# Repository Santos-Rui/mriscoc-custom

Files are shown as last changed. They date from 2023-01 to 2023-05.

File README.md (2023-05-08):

# TODO

- Start end g-code

<br/><br/>
<br/><br/>

# Instructions Boreal Spring 2023

##  Compile

 - Option STM32F10ERE_creality 512k

<br/><br/>

## Base Config 

- Ender3V2-427-BLTUBL-T5-MPC (MPC -> Alternative to PID)

<br/><br/>

## Extra Z Stepepr

### pins_CREALITY_V4.h

- Commentar esta merda, ou não dá
```
(M)// #if HOTENDS > 1 || E_STEPPERS > 1
(M)//   #error "Creality V4 only supports one hotend / E-stepper. Comment out this line to continue."
(M)// #endif
```

- Free pin to have 3 free ones for extra stepper full control
```
(M) #define Z_MIN_PROBE_PIN                   PA7   // BLTouch IN
```

- Define new pins
```
(+) #define E1_ENABLE_PIN                       PB1 //(connect to ground to always enable)
(+) #define E1_STEP_PIN                         PA14 //SWCLK (STEP - pulled low)
(+) #define E1_DIR_PIN                          PA13 //SWIO  (DIR - pulled high)
```

### Configuration.h
```
(+) #define Z2_DRIVER_TYPE  TMC2208_STANDALONE   // Ender Configs - Extra Z
```
<br/><br/>

## Probe Offset 
### Configuration.h

```
(M) #define NOZZLE_TO_PROBE_OFFSET { -44, 3, -4.28 }
```
<br/><br/>

## Jerk
### Configuration.h
```
(M)  #define DEFAULT_XJERK 15.0  // Ender Configs
(M)  #define DEFAULT_YJERK 15.0  // Ender Configs
```
<br/><br/>

## Sound
### Configuration_adv.h
```
(M) //#define SOUND_ON_DEFAULT    // Buzzer/speaker default enabled state
```
<br/><br/>

## Default steps
### Configuration.h
```
(M) //#define DEFAULT_AXIS_STEPS_PER_UNIT   { 80, 80, 400, 96.6 }  // Ender Configs
```
<br/><br/>

## Temp Sensor
### Configuration.h
```
(M) #define TEMP_SENSOR_0 5  // Volcano thermistor
```
<br/><br/>

## Live Move
### dwin.cpp
```
(M) bool EnableLiveMove = true;
```
<br/><br/>

## Max/Min Positions
### Configuration.h

```
// The size of the printable area
#define X_BED_SIZE 230  // MRiscoC Max usable bed size
#define Y_BED_SIZE 230  // MRiscoC Max usable bed size
```
```
(M)#define X_MAX_POS 249
(M)#define Y_MAX_POS 230  
(M)#define Z_MAX_POS 249 
```
<br/><br/>

 ## Mesh
### Configuration.h

```
(M) #define MESH_INSET 10           
(M) #define GRID_MAX_POINTS_X 7     
```
### Configuration_adv.h
```
#define X_MIN_POS 0  // MRiscoC Stock physical limit
#define Y_MIN_POS 0  // MRiscoC Stock physical limit
(M)#define Z_MIN_POS 0
(M)#define Y_MAX_POS 220  // 
(M)#define Z_MAX_POS 249  // 
```
<br/><br/>

 ## Tramming
### Configuration.h

```
(M)  #define BED_TRAMMING_INSET_LFRB { 10, 10, 10, 10 }    
```

<br/><br/>

## Temps

### Configuration.h

```
(M) #define PROBING_BED_TEMP     60
(M)  #define LEVELING_BED_TEMP     60
```

<br/><br/>

 ## Bed PID
### Configuration.h

```
(M)  #define DEFAULT_bedKp 203.80
(M)  #define DEFAULT_bedKi 39.81
(M)  #define DEFAULT_bedKd 695.64
```

<br/><br/>

 ## HotEnd MPC
### Configuration.h

```
(M)   #define MPC_BLOCK_HEAT_CAPACITY { 16.42 }           // (J/K) Heat block heat capacities.
(M)   #define MPC_SENSOR_RESPONSIVENESS { 0.1312 }         // (K/s per ∆K) Rate of change of sensor temperature from heat block.
(M)   #define MPC_AMBIENT_XFER_COEFF { 0.0842 }           // (W/K) Heat transfer coefficients from heat block to room air with fan off.
(M)   #define MPC_AMBIENT_XFER_COEFF_FAN255 { 0.1027 }  // (W/K) Heat transfer coefficients from heat block to room air with fan on full.
```

<br/><br/>

 ## Stepper Timeout
### Configuration_adv.h

```
#define DEFAULT_STEPPER_DEACTIVE_TIME 900
```

<br/><br/>

 ## Pause
### Configuration_adv.h

```
#define ADVANCED_PAUSE_FEATURE  // MRiscoC Enabled
#if ENABLED(ADVANCED_PAUSE_FEATURE)
  #define PAUSE_PARK_RETRACT_FEEDRATE         50  // (mm/s) Initial retract feedrate.
  #define PAUSE_PARK_RETRACT_LENGTH            5  // (mm) Initial retract.
                                                  // This short retract is done immediately, before parking the nozzle.
  #define FILAMENT_CHANGE_UNLOAD_FEEDRATE     20  // (mm/s) Unload filament feedrate. This can be pretty fast.  // MRiscoC Increased filament unload speed
  #define FILAMENT_CHANGE_UNLOAD_ACCEL        25  // (mm/s^2) Lower acceleration may allow a faster feedrate.
  #define FILAMENT_CHANGE_UNLOAD_LENGTH      370  // (mm) The length of filament for a complete unload.
                                                  //   For Bowden, the full length of the tube and nozzle.
                                                  //   For direct drive, the full length of the nozzle.
                                                  //   Set to 0 for manual unloading.
  #define FILAMENT_CHANGE_SLOW_LOAD_FEEDRATE   6  // (mm/s) Slow move when starting load.
  #define FILAMENT_CHANGE_SLOW_LOAD_LENGTH     0  // (mm) Slow length, to allow time to insert material.
                                                  // 0 to disable start loading and skip to fast load only
  #define FILAMENT_CHANGE_FAST_LOAD_FEEDRATE   12  // (mm/s) Load filament feedrate. This can be pretty fast.  // MRiscoC Increased filament load speed
  #define FILAMENT_CHANGE_FAST_LOAD_ACCEL     25  // (mm/s^2) Lower acceleration may allow a faster feedrate.
  #define FILAMENT_CHANGE_FAST_LOAD_LENGTH     320  // (mm) Load length of filament, from extruder gear to nozzle.
                                                  //   For Bowden, the full length of the tube and nozzle.
                                                  //   For direct drive, the full length of the nozzle.
  //#define ADVANCED_PAUSE_CONTINUOUS_PURGE       // Purge continuously up to the purge length until interrupted.
  #define ADVANCED_PAUSE_PURGE_FEEDRATE        3  // (mm/s) Extrude feedrate (after loading). Should be slower than load feedrate.
  #define ADVANCED_PAUSE_PURGE_LENGTH         30  // (mm) Length to extrude after loading.
                                                  //   Set to 0 for manual extrusion.
                                                  //   Filament can be extruded repeatedly from the Filament Change menu
                                                  //   until extrusion is consistent, and to purge old filament.
  #define ADVANCED_PAUSE_RESUME_PRIME          0  // (mm) Extra distance to prime nozzle after returning from park.
  //#define ADVANCED_PAUSE_FANS_PAUSE             // Turn off print-cooling fans while the machine is paused.

                                                  // Filament Unload does a Retract, Delay, and Purge first:
  #define FILAMENT_UNLOAD_PURGE_RETRACT       13  // (mm) Unload initial retract length.
  #define FILAMENT_UNLOAD_PURGE_DELAY       5000  // (ms) Delay for the filament to cool after retract.
  #define FILAMENT_UNLOAD_PURGE_LENGTH         8  // (mm) An unretract is done, then this length is purged.
  #define FILAMENT_UNLOAD_PURGE_FEEDRATE      25  // (mm/s) feedrate to purge before unload

  #define PAUSE_PARK_NOZZLE_TIMEOUT           300 // (seconds) Time limit before the nozzle is turned off for safety.
  #define FILAMENT_CHANGE_ALERT_BEEPS         10  // Number of alert beeps to play when a response is needed.
  #define PAUSE_PARK_NO_STEPPER_TIMEOUT           // Enable for XYZ steppers to stay powered on during filament change.
  //#define FILAMENT_CHANGE_RESUME_ON_INSERT      // Automatically continue / load filament when runout sensor is triggered again.
  //#define PAUSE_REHEAT_FAST_RESUME              // Reduce number of waits by not prompting again post-timeout before continuing.

  #define PARK_HEAD_ON_PAUSE                    // Park the nozzle during pause and filament change.  // MRiscoC Enabled park head when pause command was issued
  //#define HOME_BEFORE_FILAMENT_CHANGE           // If needed, home before parking for filament change

  #define FILAMENT_LOAD_UNLOAD_GCODES           // Add M701/M702 Load/Unload G-codes, plus Load/Unload in the LCD Prepare menu.  // MRiscoC Enabled load/unload Filament G-codes
  //#define FILAMENT_UNLOAD_ALL_EXTRUDERS         // Allow M702 to unload all extruders above a minimum target temp (as set by M302)
#endif
```

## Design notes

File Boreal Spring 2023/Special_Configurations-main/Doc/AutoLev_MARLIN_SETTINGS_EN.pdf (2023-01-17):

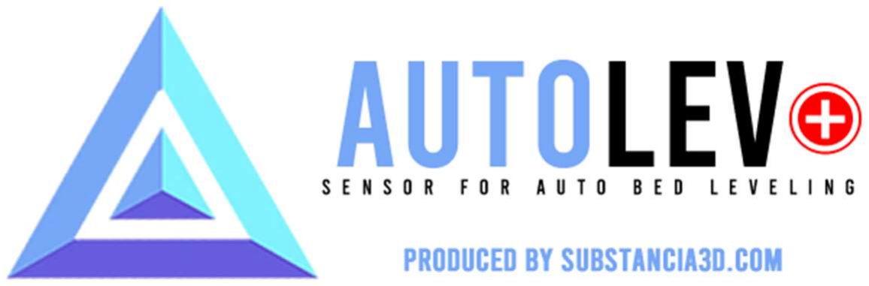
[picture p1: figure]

## Configuration on Configuration.h

#define Z_MIN_PROBE_USES_Z_MIN_ENDSTOP_PIN

#define FIX_MOUNTED_PROBE

#define X_PROBE_OFFSET_FROM_EXTRUDER 0 // X offset: -left +right [of the nozzle] #define Y_PROBE_OFFSET_FROM_EXTRUDER 0 // Y offset: -front +behind [the nozzle] #define Z_PROBE_OFFSET_FROM_EXTRUDER 0 // Z offset: -below +above [the nozzle] #define AUTO_BED_LEVELING_BILINEAR

#define Z_SAFE_HOMING

#define MULTIPLE_PROBING 2

//#define MIN_SOFTWARE_ENDSTOP_Z
#define Z_CLEARANCE_DEPLOY_PROBE 3 // Z Clearance for Deploy/Stow #define Z_CLEARANCE_BETWEEN_PROBES 2 // Z Clearance between probe points #define Z_CLEARANCE_MULTI_PROBE 2 // Z Clearance between multiple probes

//#define Z_AFTER_PROBING | 5 // Z position after probing is done
#define Z_PROBE_LOW_POINT | -2 // Farthest distance below the trigger-point to go

before stopping

## Configuration on Configuration_adv.h

#define BABYSTEP_ZPROBE_OFFSET

#define DOUBLECLICK_FOR_Z_BABYSTEPPING

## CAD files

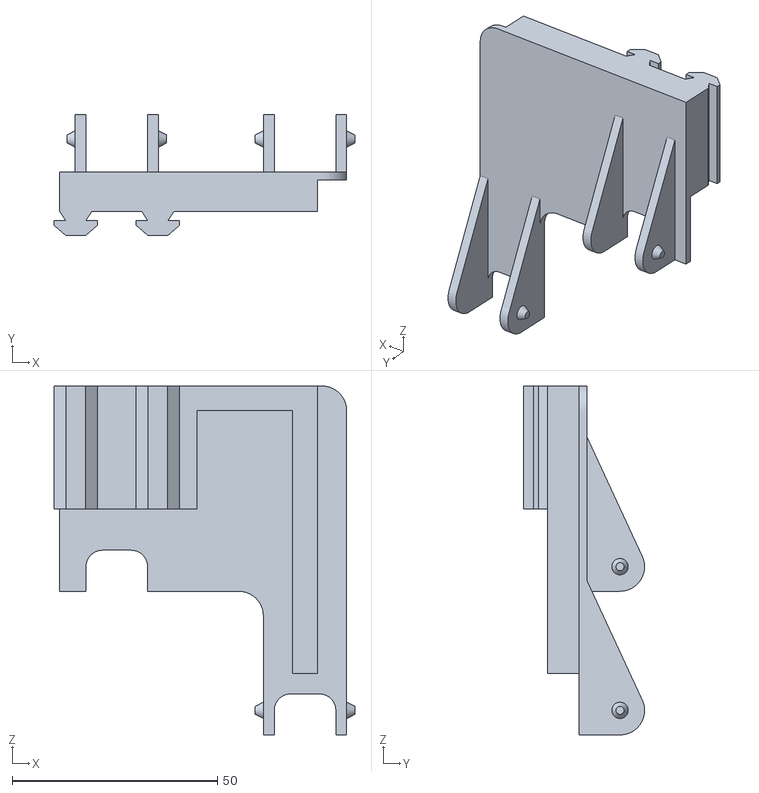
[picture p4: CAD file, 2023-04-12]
STL's/Cable Chains/CablePlateV2 v1.stl
73.3 x 29.5 x 85.0

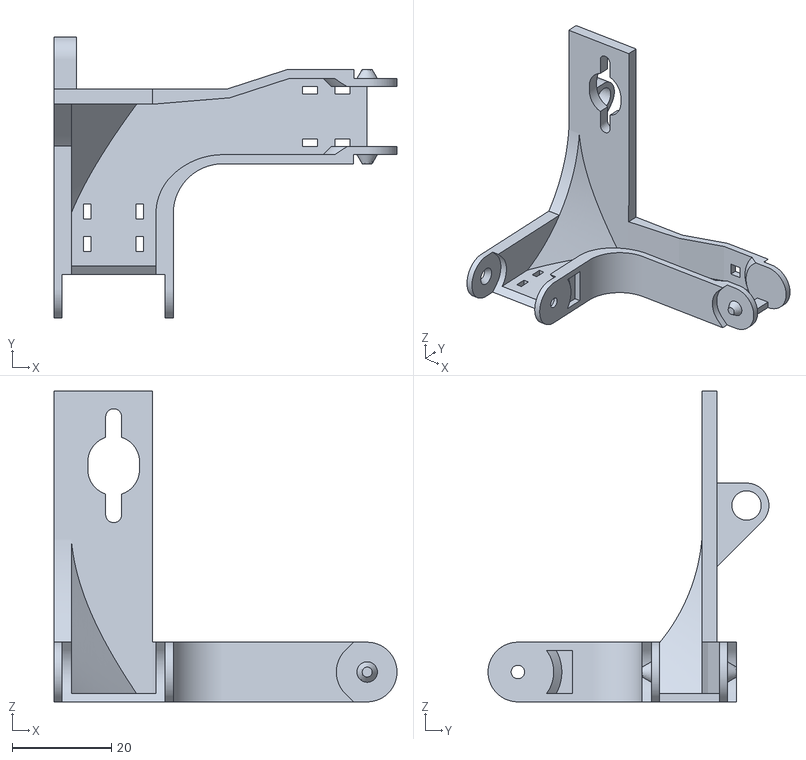
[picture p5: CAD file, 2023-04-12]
STL's/Cable Chains/Not sure wich/extruder-mount-30mm-stock.stl
69.0 x 56.5 x 62.5

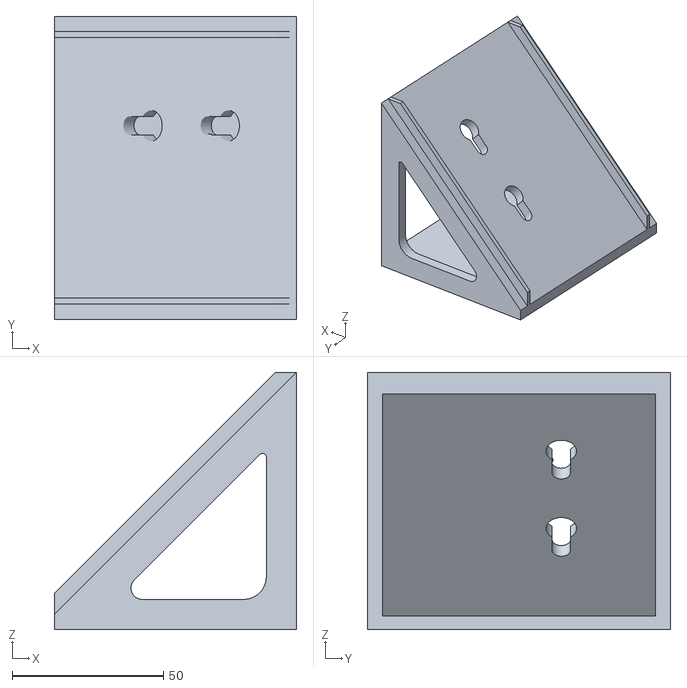
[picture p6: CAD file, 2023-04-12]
STL's/External Screen/Control-Panel-Holder-Remix-Hollow v2.stl
80.0 x 100.1 x 85.0

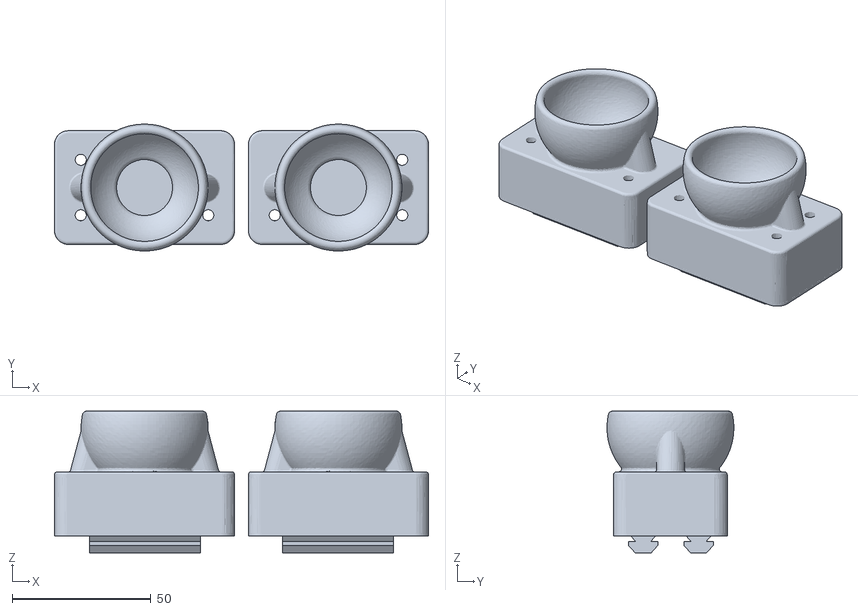
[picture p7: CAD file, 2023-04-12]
STL's/Feet/Squash_feet_RAISED-Diferent.stl
135.0 x 45.8 x 51.1

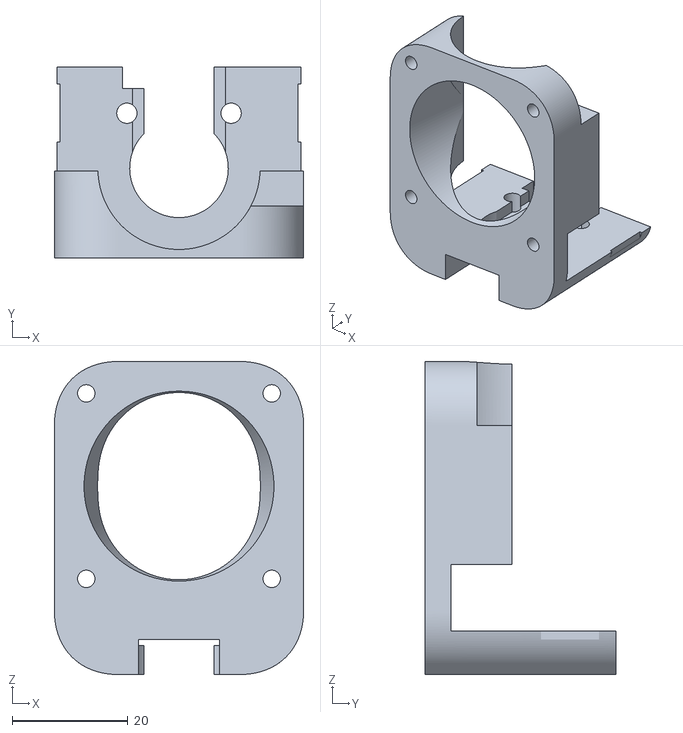
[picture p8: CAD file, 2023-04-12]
STL's/Klemco Holder/Klemco mine v12.stl
43.0 x 33.0 x 54.0

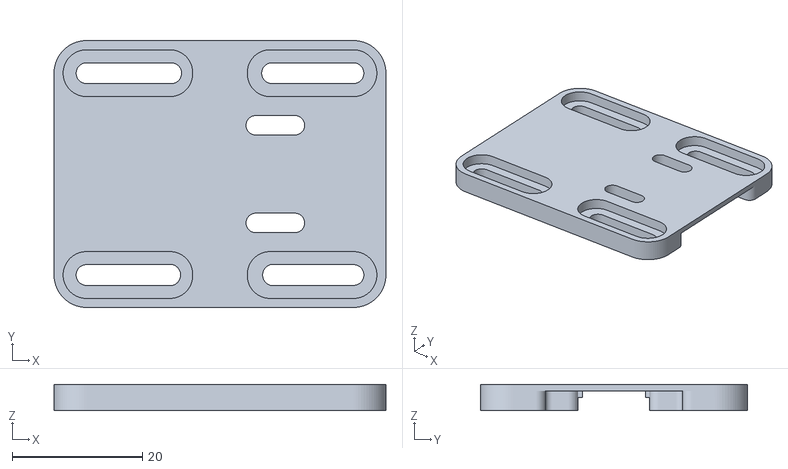
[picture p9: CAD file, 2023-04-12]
STL's/Linear Rails/X Axis/Adjsutable_X_endstop_top v7.stl
51.0 x 41.0 x 4.00

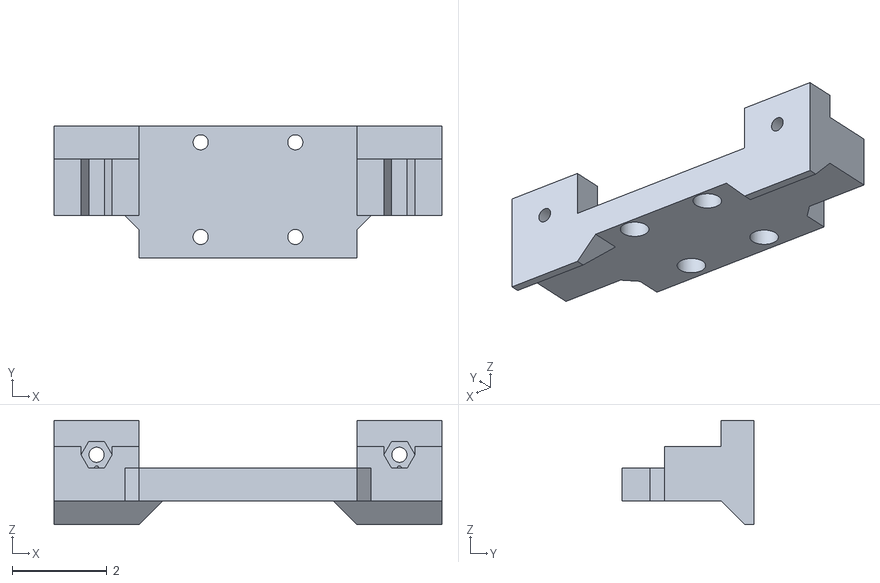
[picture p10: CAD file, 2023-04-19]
STL's/Linear Rails/Y Axis/Y Rail Final v5.stl
8.20 x 2.80 x 2.20

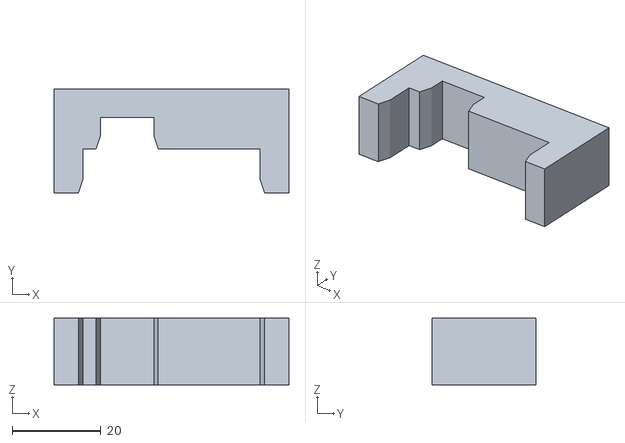
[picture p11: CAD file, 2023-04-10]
STL's/Linear Rails/Z Axis/2040_12mm_linear_rail_alignment_clip.stl
53.0 x 23.5 x 15.0

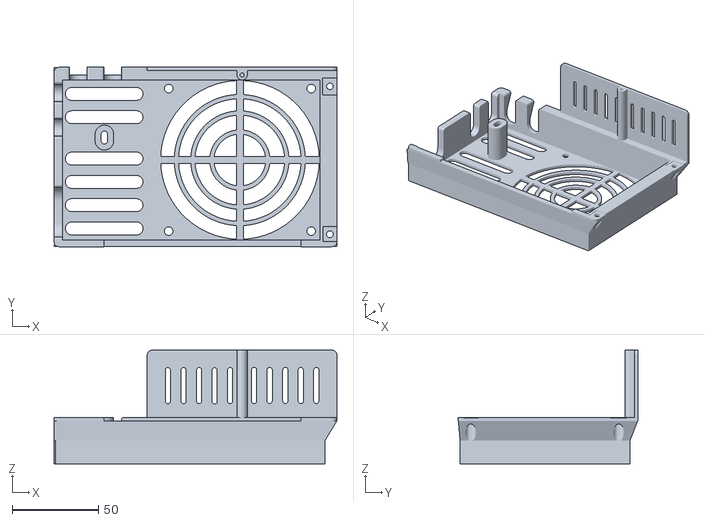
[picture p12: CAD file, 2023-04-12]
STL's/Noctuas Under/MOBO_coverx10 v9.stl
164.0 x 104.0 x 66.0

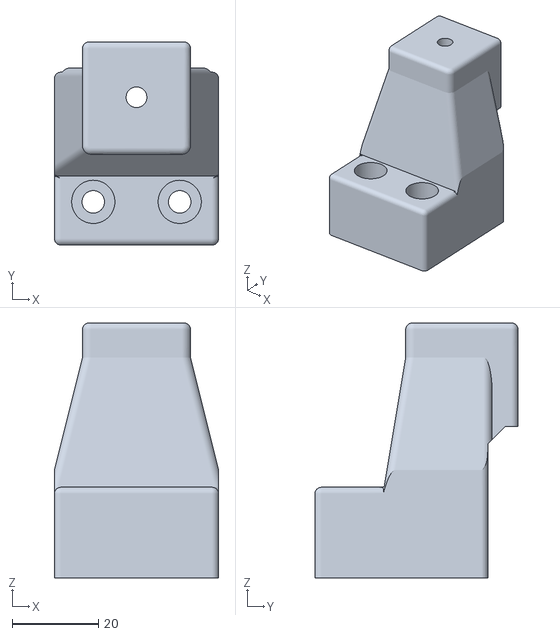
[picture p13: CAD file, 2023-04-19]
STL's/Y Belt Tensioner/Y Belt Tensioner v8.stl
38.0 x 47.0 x 59.0

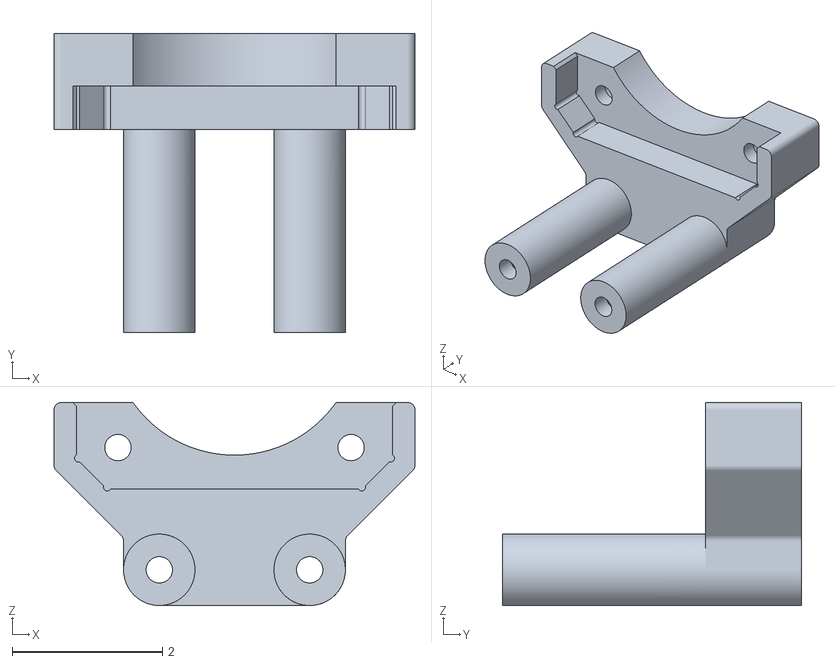
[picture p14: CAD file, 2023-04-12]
STL's/Z Holder/ZAxisStepperMountTop_V1 v6.stl
4.80 x 3.97 x 2.70

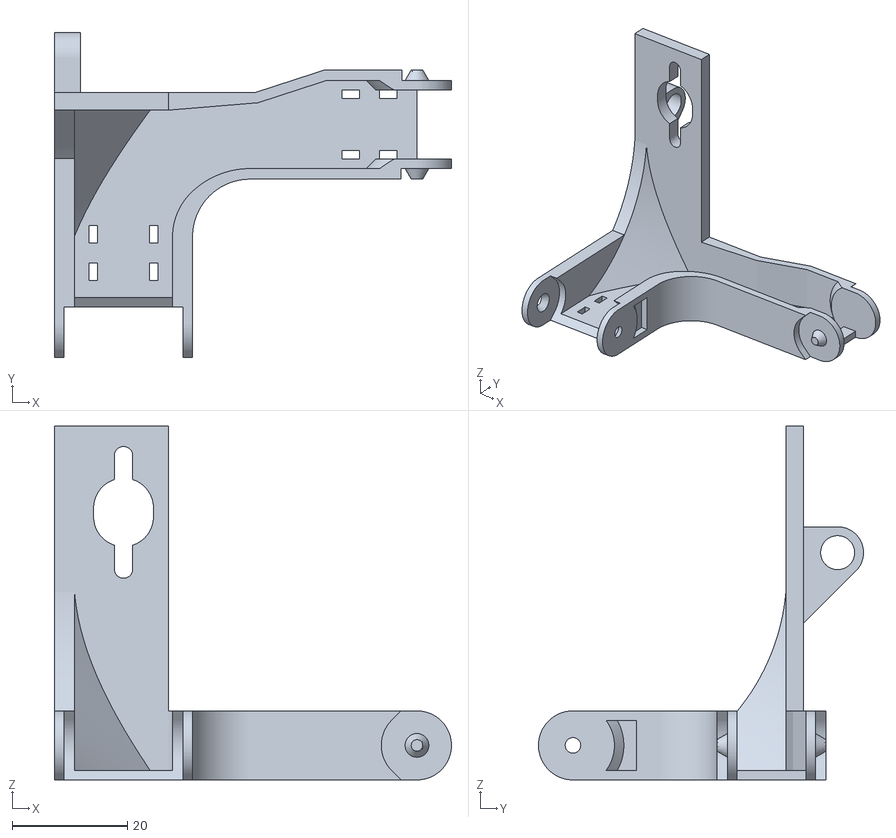
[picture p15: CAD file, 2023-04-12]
STL's/Cable Chains/Not sure wich/extruder-mount-29mm-alu.stl
69.0 x 56.5 x 61.5

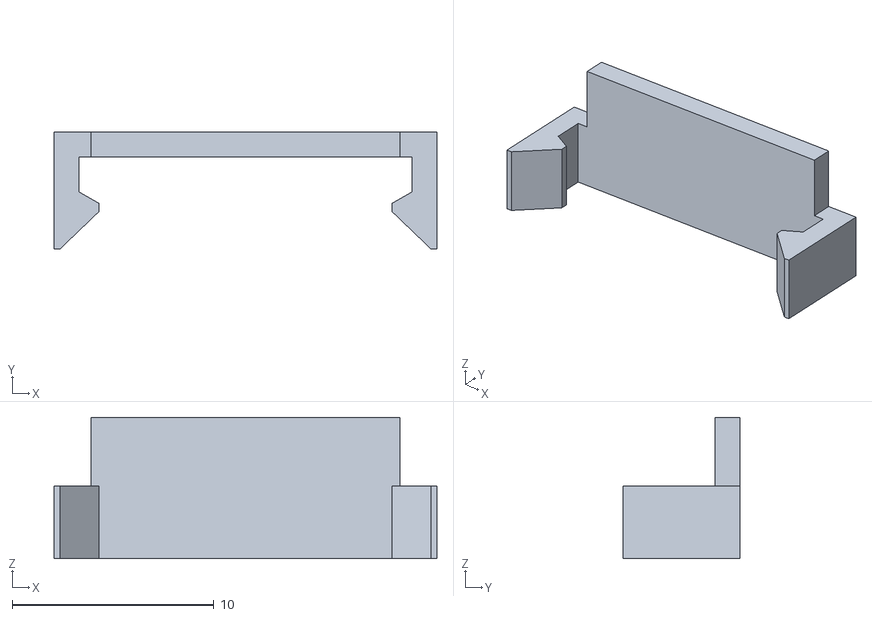
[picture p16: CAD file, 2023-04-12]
STL's/Cable Chains/slim-link_cover.stl
19.0 x 5.80 x 7.00

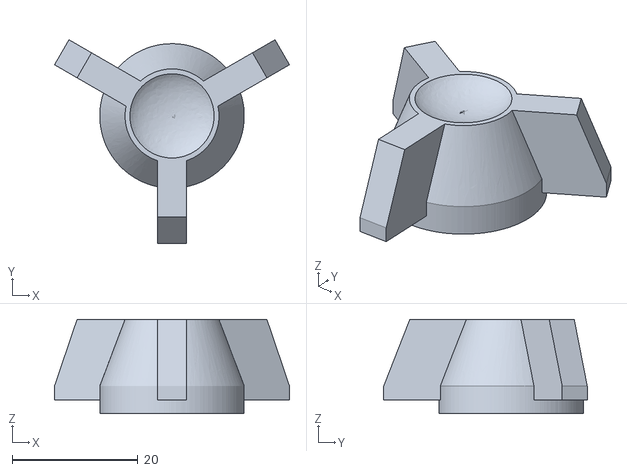
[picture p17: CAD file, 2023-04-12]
STL's/External Screen/Ender_3_Prusa-like_Knob_v2.stl
37.4 x 32.4 x 15.0

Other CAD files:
STL's/Klemco Holder/suport fang lateral v7.stl
STL's/Linear Rails/X Axis/Ad_X_endstop_side v2.stl
STL's/Linear Rails/Y Axis/Y Rail Final EndStop v3.stl
STL's/Linear Rails/Z Axis/Bottom Rail.stl
STL's/Cable Chains/Not sure wich/extruder-mount-27mm-alu-dd.stl
STL's/Cable Chains/Not sure wich/extruder-mount-27mm-alu.stl
STL's/Cable Chains/Not sure wich/extruder-mount-27mm-stock.stl
STL's/Cable Chains/Not sure wich/extruder-mount-28mm-alu-dd.stl
STL's/Cable Chains/Not sure wich/extruder-mount-28mm-alu.stl
STL's/Cable Chains/Not sure wich/extruder-mount-28mm-stock.stl
STL's/Cable Chains/Not sure wich/extruder-mount-29mm-alu-dd.stl
STL's/Cable Chains/Not sure wich/extruder-mount-29mm-stock.stl
STL's/Cable Chains/Not sure wich/extruder-mount-30mm-alu-dd.stl
STL's/Cable Chains/Not sure wich/extruder-mount-30mm-alu.stl
STL's/Cable Chains/Not sure wich/extruder-mount-31mm-alu-dd.stl
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

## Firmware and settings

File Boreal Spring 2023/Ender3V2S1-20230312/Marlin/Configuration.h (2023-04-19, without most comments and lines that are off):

#pragma once
#define CONFIGURATION_H_VERSION 02010300
#define STRING_CONFIG_H_AUTHOR "Miguel A. Risco-Castillo (MRiscoC)" // Who made the changes.
#define CUSTOM_VERSION_FILE Version.h // Path from the root directory (no quotes)
#define SHOW_BOOTSCREEN
  #define MOTHERBOARD BOARD_CREALITY_V427  // Board v4.2.7
#define SERIAL_PORT 1  // Ender Configs
#define NO_AUTO_ASSIGN_WARNING  // Disable serial warnings
#define BAUDRATE 250000  // MRiscoC increase serial performace
#define BAUD_RATE_GCODE     // Enable G-code M575 to set the baud rate  // MRiscoC Enables change the baudrate
#define CUSTOM_MACHINE_NAME "Ender3V2-427-BLTUBL-T5-MPC"
#define X_DRIVER_TYPE  TMC2208_STANDALONE  // Ender Configs
#define Y_DRIVER_TYPE  TMC2208_STANDALONE  // Ender Configs
#define Z_DRIVER_TYPE  TMC2208_STANDALONE  // Ender Configs
#define Z2_DRIVER_TYPE  TMC2208_STANDALONE   // Ender Configs - Extra Z
#define E0_DRIVER_TYPE TMC2208_STANDALONE  // Ender Configs
#define EXTRUDERS 1
#define DEFAULT_NOMINAL_FILAMENT_DIA 1.75
#define TEMP_SENSOR_0 5  // Volcano thermistor
#define TEMP_SENSOR_1 0
#define TEMP_SENSOR_2 0
#define TEMP_SENSOR_3 0
#define TEMP_SENSOR_4 0
#define TEMP_SENSOR_5 0
#define TEMP_SENSOR_6 0
#define TEMP_SENSOR_7 0
#define TEMP_SENSOR_BED 1  // Ender Configs
#define TEMP_SENSOR_PROBE 0
#define TEMP_SENSOR_CHAMBER 0
#define TEMP_SENSOR_COOLER 0
#define TEMP_SENSOR_BOARD 0
#define TEMP_SENSOR_REDUNDANT 0
#define DUMMY_THERMISTOR_998_VALUE  25
#define DUMMY_THERMISTOR_999_VALUE 100
#if TEMP_SENSOR_IS_MAX_TC(0)
  #define MAX31865_SENSOR_OHMS_0      100 // (Ω) Typically 100 or 1000 (PT100 or PT1000)
  #define MAX31865_CALIBRATION_OHMS_0 430 // (Ω) Typically 430 for Adafruit PT100; 4300 for Adafruit PT1000
#endif
#if TEMP_SENSOR_IS_MAX_TC(1)
  #define MAX31865_SENSOR_OHMS_1      100
  #define MAX31865_CALIBRATION_OHMS_1 430
#endif
#if TEMP_SENSOR_IS_MAX_TC(2)
  #define MAX31865_SENSOR_OHMS_2      100
  #define MAX31865_CALIBRATION_OHMS_2 430
#endif
#if HAS_E_TEMP_SENSOR
  #define TEMP_RESIDENCY_TIME         10  // (seconds) Time to wait for hotend to "settle" in M109
  #define TEMP_WINDOW                  1  // (°C) Temperature proximity for the "temperature reached" timer
  #define TEMP_HYSTERESIS              3  // (°C) Temperature proximity considered "close enough" to the target
#endif
#if TEMP_SENSOR_BED
  #define TEMP_BED_RESIDENCY_TIME     10  // (seconds) Time to wait for bed to "settle" in M190
  #define TEMP_BED_WINDOW              1  // (°C) Temperature proximity for the "temperature reached" timer
  #define TEMP_BED_HYSTERESIS          3  // (°C) Temperature proximity considered "close enough" to the target
#endif
#if TEMP_SENSOR_CHAMBER
  #define TEMP_CHAMBER_RESIDENCY_TIME 10  // (seconds) Time to wait for chamber to "settle" in M191
  #define TEMP_CHAMBER_WINDOW          1  // (°C) Temperature proximity for the "temperature reached" timer
  #define TEMP_CHAMBER_HYSTERESIS      3  // (°C) Temperature proximity considered "close enough" to the target
#endif
#if TEMP_SENSOR_REDUNDANT
  #define TEMP_SENSOR_REDUNDANT_SOURCE    E1  // The sensor that will provide the redundant reading.
  #define TEMP_SENSOR_REDUNDANT_TARGET    E0  // The sensor that we are providing a redundant reading for.
  #define TEMP_SENSOR_REDUNDANT_MAX_DIFF  10  // (°C) Temperature difference that will trigger a print abort.
#endif
#define HEATER_0_MINTEMP   5  // Ender Configs  // Volcano thermistor
#define HEATER_1_MINTEMP   5
#define HEATER_2_MINTEMP   5
#define HEATER_3_MINTEMP   5
#define HEATER_4_MINTEMP   5
#define HEATER_5_MINTEMP   5
#define HEATER_6_MINTEMP   5
#define HEATER_7_MINTEMP   5
#define BED_MINTEMP        0  // Ender Configs
#define CHAMBER_MINTEMP    5
#define HEATER_0_MAXTEMP 300  // Volcano thermistor
#define HEATER_1_MAXTEMP 275
#define HEATER_2_MAXTEMP 275
#define HEATER_3_MAXTEMP 275
#define HEATER_4_MAXTEMP 275
#define HEATER_5_MAXTEMP 275
#define HEATER_6_MAXTEMP 275
#define HEATER_7_MAXTEMP 275
#define BED_MAXTEMP      120  // Ender3V2 Configs
#define CHAMBER_MAXTEMP  60
#define HOTEND_OVERSHOOT 15   // (°C) Forbid temperatures over MAXTEMP - OVERSHOOT
#define BED_OVERSHOOT    10   // (°C) Forbid temperatures over MAXTEMP - OVERSHOOT
#define COOLER_OVERSHOOT  2   // (°C) Forbid temperatures closer than OVERSHOOT
#define MPCTEMP        // ** EXPERIMENTAL **
#define BANG_MAX 255     // Limits current to nozzle while in bang-bang mode; 255=full current
#define PID_MAX BANG_MAX // Limits current to nozzle while PID is active (see PID_FUNCTIONAL_RANGE below); 255=full current
#define PID_K1 0.95      // Smoothing factor within any PID loop
  #define MPC_MAX BANG_MAX                            // (0..255) Current to nozzle while MPC is active.
  #define MPC_HEATER_POWER { 40.0f }                  // (W) Heat cartridge powers.
  #define MPC_INCLUDE_FAN                             // Model the fan speed?
  #define MPC_BLOCK_HEAT_CAPACITY { 16.42 }           // (J/K) Heat block heat capacities.
  #define MPC_SENSOR_RESPONSIVENESS { 0.1312 }         // (K/s per ∆K) Rate of change of sensor temperature from heat block.
  #define MPC_AMBIENT_XFER_COEFF { 0.0842 }           // (W/K) Heat transfer coefficients from heat block to room air with fan off.
    #define MPC_AMBIENT_XFER_COEFF_FAN255 { 0.1027 }  // (W/K) Heat transfer coefficients from heat block to room air with fan on full.
  #define FILAMENT_HEAT_CAPACITY_PERMM { 5.6e-3f }    // 0.0056 J/K/mm for 1.75mm PLA (0.0149 J/K/mm for 2.85mm PLA).
  #define MPC_SMOOTHING_FACTOR 0.5f                   // (0.0...1.0) Noisy temperature sensors may need a lower value for stabilization.
  #define MPC_MIN_AMBIENT_CHANGE 1.0f                 // (K/s) Modeled ambient temperature rate of change, when correcting model inaccuracies.
  #define MPC_STEADYSTATE 0.5f                        // (K/s) Temperature change rate for steady state logic to be enforced.
  #define MPC_TUNING_POS { X_CENTER, Y_CENTER, 1.0f } // (mm) M306 Autotuning position, ideally bed center at first layer height.
  #define MPC_TUNING_END_Z 10.0f                      // (mm) M306 Autotuning final Z position.
#define PIDTEMPBED  // Ender Configs
#define MAX_BED_POWER 255 // limits duty cycle to bed; 255=full current
  #define DEFAULT_bedKp 203.80
  #define DEFAULT_bedKi 39.81
  #define DEFAULT_bedKd 695.64
#define MAX_CHAMBER_POWER 255 // limits duty cycle to chamber heater; 255=full current
  #define PID_FUNCTIONAL_RANGE 10 // If the temperature difference between the target temperature and the actual temperature
#define PREVENT_COLD_EXTRUSION
#define EXTRUDE_MINTEMP 180  // MRiscoC Customizable by menu
#define PREVENT_LENGTHY_EXTRUDE
#define EXTRUDE_MAXLENGTH 1000  // Ender Configs
#define THERMAL_PROTECTION_HOTENDS // Enable thermal protection for all extruders
#define THERMAL_PROTECTION_BED     // Enable thermal protection for the heated bed
#define USE_XMIN_PLUG
#define USE_YMIN_PLUG
#define USE_ZMIN_PLUG
#define ENDSTOPPULLUPS
#define X_MIN_ENDSTOP_INVERTING false // Set to true to invert the logic of the endstop.
#define Y_MIN_ENDSTOP_INVERTING false // Set to true to invert the logic of the endstop.
#define Z_MIN_ENDSTOP_INVERTING false // Set to true to invert the logic of the endstop.
#define I_MIN_ENDSTOP_INVERTING false // Set to true to invert the logic of the endstop.
#define J_MIN_ENDSTOP_INVERTING false // Set to true to invert the logic of the endstop.
#define K_MIN_ENDSTOP_INVERTING false // Set to true to invert the logic of the endstop.
#define U_MIN_ENDSTOP_INVERTING false // Set to true to invert the logic of the endstop.
#define V_MIN_ENDSTOP_INVERTING false // Set to true to invert the logic of the endstop.
#define W_MIN_ENDSTOP_INVERTING false // Set to true to invert the logic of the endstop.
#define X_MAX_ENDSTOP_INVERTING false // Set to true to invert the logic of the endstop.
#define Y_MAX_ENDSTOP_INVERTING false // Set to true to invert the logic of the endstop.
#define Z_MAX_ENDSTOP_INVERTING false // Set to true to invert the logic of the endstop.
#define I_MAX_ENDSTOP_INVERTING false // Set to true to invert the logic of the endstop.
#define J_MAX_ENDSTOP_INVERTING false // Set to true to invert the logic of the endstop.
#define K_MAX_ENDSTOP_INVERTING false // Set to true to invert the logic of the endstop.
#define U_MAX_ENDSTOP_INVERTING false // Set to true to invert the logic of the endstop.
#define V_MAX_ENDSTOP_INVERTING false // Set to true to invert the logic of the endstop.
#define W_MAX_ENDSTOP_INVERTING false // Set to true to invert the logic of the endstop.
#define Z_MIN_PROBE_ENDSTOP_INVERTING false // Set to true to invert the logic of the probe.
#define ENDSTOP_INTERRUPTS_FEATURE  // Ender Configs
#define DEFAULT_AXIS_STEPS_PER_UNIT   { 80, 80, 400, 96.6 }  // Ender Configs
#define DEFAULT_MAX_FEEDRATE          { 300, 300, 25, 60 }  // Ender Configs
#define LIMITED_MAX_FR_EDITING        // Limit edit via M203 or LCD to DEFAULT_MAX_FEEDRATE * 2  // MRiscoC allows higher limits
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

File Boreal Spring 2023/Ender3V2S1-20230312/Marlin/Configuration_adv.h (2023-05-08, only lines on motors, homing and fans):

#define E0_AUTO_FAN_PIN -1  // Ender3V2 Configs
#define E1_AUTO_FAN_PIN -1
#define E2_AUTO_FAN_PIN -1
#define E3_AUTO_FAN_PIN -1
#define E4_AUTO_FAN_PIN -1
#define E5_AUTO_FAN_PIN -1
#define E6_AUTO_FAN_PIN -1
#define E7_AUTO_FAN_PIN -1
#define CHAMBER_AUTO_FAN_PIN -1
#define COOLER_AUTO_FAN_PIN -1
#define HOMING_BUMP_MM      { 5, 5, 2 }       // (linear=mm, rotational=°) Backoff from endstops after first bump
#define HOMING_BUMP_DIVISOR { 2, 2, 4 }       // Re-Bump Speed Divisor (Divides the Homing Feedrate)
#define QUICK_HOME                          // If G28 contains XY do a diagonal move first  // Ender Configs
  #define HOME_AFTER_G34
#define MICROSTEP_MODES { 16, 16, 16, 16, 16, 16 } // [1,2,4,8,16]
  #define BABYSTEP_WITHOUT_HOMING  // MRiscoC Enabled BbS without home
#define ADVANCED_OK  // MRiscoC better management of buffer by host
#define ADVANCED_PAUSE_FEATURE  // MRiscoC Enabled
  #define ADVANCED_PAUSE_PURGE_FEEDRATE        1  // (mm/s) Extrude feedrate (after loading). Should be slower than load feedrate.
  #define ADVANCED_PAUSE_PURGE_LENGTH         15  // (mm) Length to extrude after loading.
  #define ADVANCED_PAUSE_RESUME_PRIME          0  // (mm) Extra distance to prime nozzle after returning from park.

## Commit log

2023-01-17 Base version
    [Configuration.h, Configuration_adv.h, Configuration_advbASE.h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]
2023-02-12 2nd stepper!
    [Configuration.h, Configuration_adv.h]
2023-04-03 folder refactor
    [Configuration.h, Configuration_adv.h, Configuration_advbASE.h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]
2023-04-03 prepare for new version
    [Configuration.h, Configuration_adv.h, Configuration_advbASE.h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]
2023-04-03 Boreal Spring Base Version No Configs
    [Configuration.h, Configuration_adv.h, T5UIC1.CFG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]
2023-04-04 Add base configs
    [Configuration.h, Configuration_adv.h]
2023-04-04 Extra stepper with markdown on readme
    [Configuration.h]
2023-04-05 Probe offset
    [Configuration.h]
2023-04-05 Sound fix
    [Configuration.h, Configuration_adv.h]
2023-04-05 Temp sensor
2023-04-05 Max limits and mesh
    [Configuration.h, Configuration_adv.h]
2023-04-05 Bed leveling temp
    [Configuration.h]
2023-04-05 Z offset
    [Configuration.h]
2023-04-05 Idle timout
    [Configuration_adv.h]
2023-04-10 Rails STL files
    [2040_12mm_linear_rail_alignment_clip.stl, Bottom Rail.stl, Y rail holder custm endstop v2.stl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]
2023-04-12 Add STIL's
    [Ad_X_endstop_side v2.stl, Adjsutable_X_endstop_top v7.stl, CablePlateV2 v1.stl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]
2023-04-18 bed size
    [Configuration.h, Configuration_adv.h]
2023-04-19 Bed PID
    [Configuration.h]
2023-04-19 hotend mpc
    [Configuration.h]
2023-04-19 stepper timeout
    [Configuration_adv.h]
2023-04-19 Rail stls
    [Y Belt Tensioner v6.stl, Y Belt Tensioner v8.stl, Y Rail Final EndStop v3.stl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]

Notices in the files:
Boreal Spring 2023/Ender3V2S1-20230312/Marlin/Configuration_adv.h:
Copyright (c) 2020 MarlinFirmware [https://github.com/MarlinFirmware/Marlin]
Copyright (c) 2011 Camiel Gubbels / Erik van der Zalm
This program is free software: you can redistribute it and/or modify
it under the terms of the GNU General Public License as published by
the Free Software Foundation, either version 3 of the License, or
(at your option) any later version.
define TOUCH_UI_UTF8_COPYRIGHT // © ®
